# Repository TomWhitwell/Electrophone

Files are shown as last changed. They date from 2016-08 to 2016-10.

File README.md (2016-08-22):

# Electrophone

Electrophone is a Eurorack module containing a full-sized single coil guitar pickup.  

This module is a sister to the Mikrophonie Contact Mic Module and Magnetophone Tape Head Module. The Mikrophonie picks up physical vibrations, while Electrophone can hear electromagnetic vibrations. Guitar pickups are designed to convert vibrating metal (strings) into audio, but single coil pickups are also notoriously susceptible to interference of all kinds; hum from transformers, fluorescent lights or even radio signals.

This module is named after the [Epiphone Electrophone](http://www.oldfrets.com/Electrophone.html) an electric guitar from 1935.  

More information: 
- [FAQ](https://github.com/TomWhitwell/Electrophone/wiki/Music-Thing-Electrophone:-FAQ) 
- [BOM](https://github.com/TomWhitwell/Electrophone/wiki/Music-Thing-Elecrophone:-BOM)
- [Troubleshooting](https://github.com/TomWhitwell/Electrophone/wiki/Music-Thing-Electrophone:-Troubleshooting)
- [Demo video at Superbooth 16](https://youtu.be/UVMrQejVZlw?t=3m17s)

Status:  
- August 2016: Finalised circuit 
- May 2016: revised Rev 4 layout trying to get the fuzz circuit to work 
- March 2016: Demonstrated at Superbooth16 in Berlin, with Fuzz circuit bypassed. 
- December 2015: Small component changes in Pickup Board. 
- November 2015: Minor fault in Panel (pickup cutout slightly tight) and major faults in Pickup Board. Rev2 board designed and sent to fab.  
- October 2015: Rev 1 prototype boards sent to fab  



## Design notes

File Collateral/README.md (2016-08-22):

#Gerber Files 

These PCB panels are made by manually editing Gerber files using [Cenon](http://www.cenon.info/). The Eagle .brd files will not produce the finished panel designs.

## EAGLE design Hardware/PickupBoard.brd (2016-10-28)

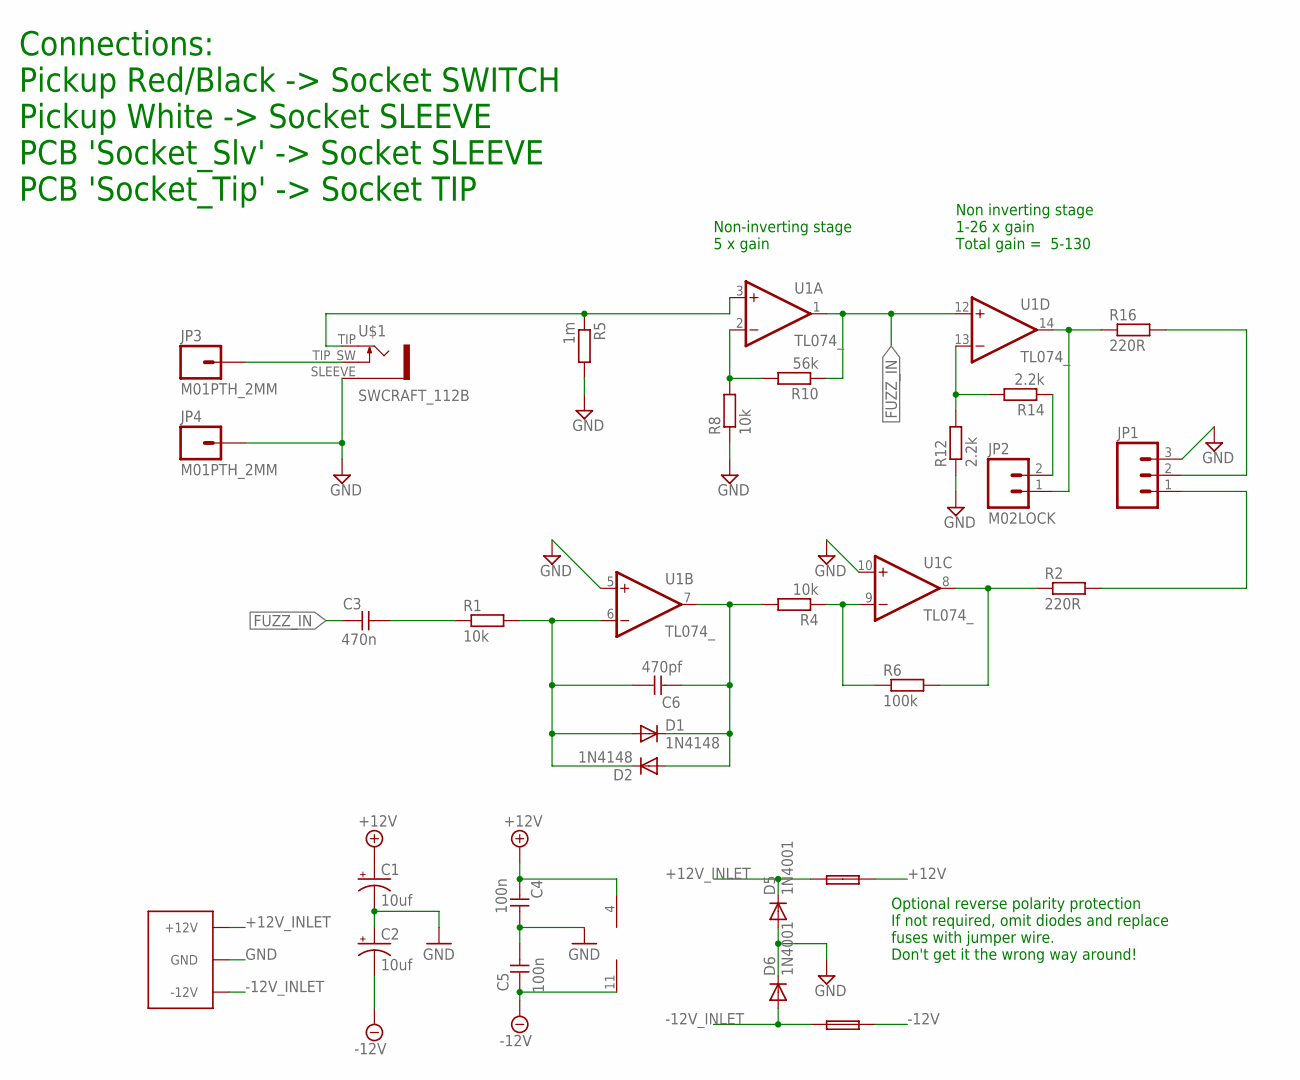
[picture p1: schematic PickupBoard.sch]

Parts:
1: FUSE; C050H075X075
C1, C2: 10uf; CPOL-RADIAL-10UF-25V
C3: 470n; C050-024X044
C4, C5: 100n; C050-024X044
C6: 470pf; C050-024X044
D1, D2: 1N4148; DO35-7
D5, D6: 1N4001; DO41-10
FUSE: FUSE; C050H075X075
JP1: M03LOCK; 1X03_LOCK
JP2: M02LOCK; 1X02_LOCK
JP3, JP4: M01PTH_2MM; 1X01_2MM
R1, R4, R8: 10k; 7MM_RESISTOR
R2, R16: 220R; 7MM_RESISTOR
R5: 1m; 7MM_RESISTOR
R6: 100k; 7MM_RESISTOR
R10: 56k; 7MM_RESISTOR
R12, R14: 2.2k; 7MM_RESISTOR
U1: TL074_; DIL14
U$1: SWCRAFT_112B; SWCRAFT_112_SLOTS
U$2: EURO_POWER_LOCK; EURO_PWR_HEADER_LOCK

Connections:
+12V: 1.2, C1.1 (+), C4.2, U1.4 (V+)
+12V_INLET: 1.1, D5.C, U$2.POS1 (+12V), U$2.POS2 (+12V)
-12V: C2.2 (-), C5.2, FUSE.2, U1.11 (V-)
-12V_INLET: D6.A, FUSE.1, U$2.NEG1 (-12V), U$2.NEG2 (-12V)
FUZZ_IN: C3.2, R10.1, U1.1 (OUT), U1.12 (+IN)
GND: C1.2 (-), C2.1 (+), C4.1, C5.1, D5.A, D6.C, JP1.3, JP4.1, R5.2, R8.1, R12.1, U1.5 (+IN), U1.10 (+IN), U$1.SLEEVE (5), U$2.GND1 (GND), U$2.GND2 (GND), U$2.GND3 (GND), U$2.GND4 (GND), U$2.GND5 (GND), U$2.GND6 (GND)
unnamed: R5.1, U1.3 (+IN), U$1.TIP (3)
unnamed: C6.2, D1.C, D2.A, R4.2, U1.7 (OUT)
unnamed: R8.2, R10.2, U1.2 (-IN)
unnamed: C6.1, D1.A, D2.C, R1.2, U1.6 (-IN)
unnamed: JP2.2, R14.1
unnamed: R12.2, R14.2, U1.13 (-IN)
unnamed: C3.1, R1.1
unnamed: JP2.1, R16.1, U1.14 (OUT)
unnamed: R4.1, R6.1, U1.9 (-IN)
unnamed: JP1.2, R16.2
unnamed: R2.1, R6.2, U1.8 (OUT)
unnamed: JP1.1, R2.2
unnamed: JP3.1, U$1.TIP_SW (4)

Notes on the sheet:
Non-inverting stage 5 x gain
Non inverting stage 1-26 x gain Total gain = 5-130
Optional reverse polarity protection If not required, omit diodes and replace fuses with jumper wire. Don't get it the wrong way around!
Connections: Pickup Red/Black -> Socket SWITCH Pickup White -> Socket SLEEVE PCB 'Socket_Slv' -> Socket SLEEVE PCB 'Socket_Tip' -> Socket TIP

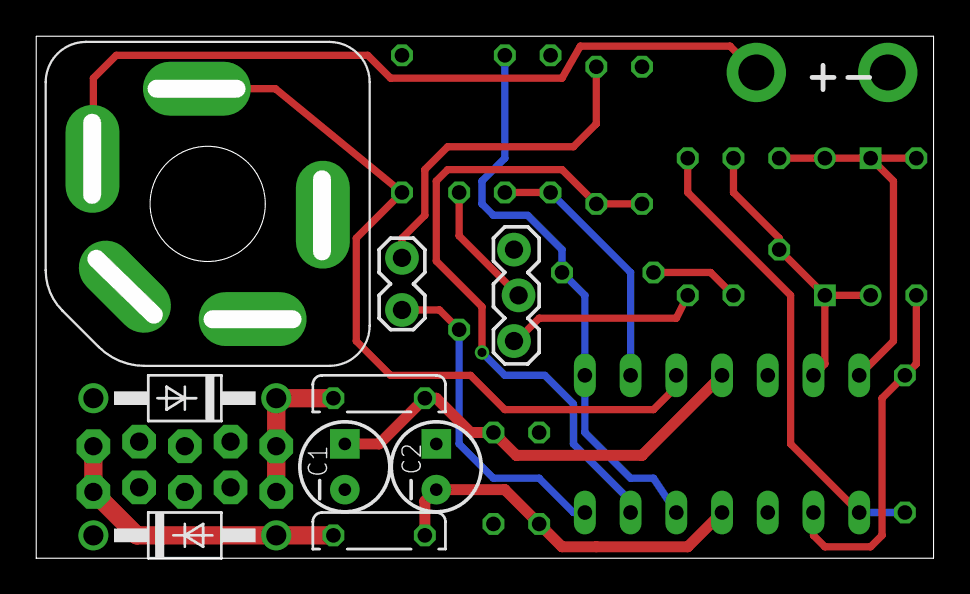
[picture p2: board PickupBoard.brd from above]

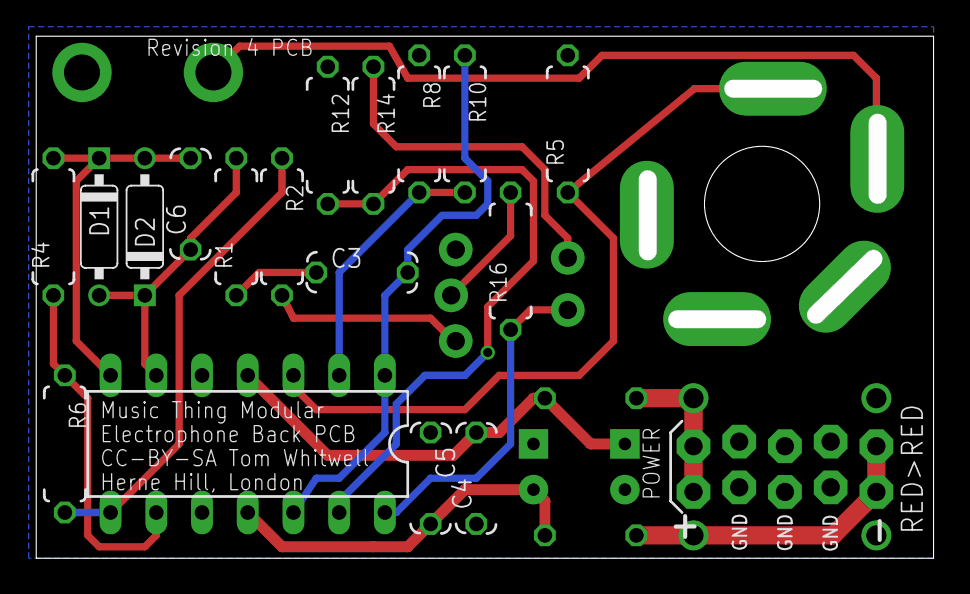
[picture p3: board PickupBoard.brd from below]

Board: 4 copper layers, 49.9 x 29.0 mm, 29 parts (20 on the bottom side), 19 nets.

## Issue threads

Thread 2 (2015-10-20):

Main board has components on the wrong sides

TomWhitwell, 2015-10-20:
What's on the front should be on the back, and vice versa

Closed 2015-11-30.

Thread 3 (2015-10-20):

Pinout on 1/4" socket is completely wrong

TomWhitwell, 2015-10-20:

Closed 2015-11-30.

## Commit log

2015-10-01 early board layout
    [PickupBoard.brd, PickupBoard.sch, PickupPanel.brd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]
2015-10-03 Building the circuit
    [PickupBoard.brd, PickupBoard.sch, PickupPanel.brd]
2015-10-04 Completed first layout
    [PickupBoard.brd, PickupBoard.sch, PickupDaughterBoard.brd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]
2015-10-04 First prototypes completed and sent to fab
    [PickupBoard.brd, PickupBoard.sch, PickupDaughterBoard.brd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]
2015-10-18 Simple alt panel
    [PickupPanel_simpler.brd, PickupPanel_simpler.sch]
2015-10-19 Grow Pickup cutout
    fixes #1
    [PickupPanel.brd, PickupPanel_simpler.brd]
2015-11-29 New Fuzz Circuit with clipping diodes
    not yet laid out
    [PickupBoard_2.brd, PickupBoard_2.sch]
2015-11-30 Rev2 Pickup Board finished and routed
    Panel and Daughterboard unchanged fixes #2, fixes #3, fixes #4
    [PickupBoard.brd, PickupBoard.sch, PickupBoard_2.brd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]
2015-12-22 notes for changes to fix high frequency oscillation
    [PickupBoard.sch]
2015-12-23 Value changes + new cap
    [PickupBoard.brd, PickupBoard.sch]
2016-01-01 Small routing changes
    [PickupBoard.brd]
2016-01-01 Update pickup cutout
    [PickupPanel.brd]
2016-04-10 Reworked layout to reduce noise / feedback
    [PickupBoard.brd, PickupBoard.sch]
2016-05-08 Rev 4 pcb
    [PickupBoard.brd, PickupBoard.sch, PickupDaughterBoard.brd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]
2016-08-22 Clean up files
    [PickupDaughterBoard.brd, PickupDaughterBoard.sch, PickupPanel.brd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]
2016-08-22 Create Gerbers and Edit
    [PickupPanel_simpler.brd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]
2016-08-22 Rename folder
    [PickupBoard.drills.xln, PickupDaughterBoard.drills.xln, PickupPanel.drills.xln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]
2016-08-22 Update panel eagle files removing old logos
    [PickupPanel.brd, PickupPanel_simpler.brd]
2016-10-28 Change name on back pcbs
    [PickupBoard.brd]
2017-02-27 Remove old Gerber
    [PickupBoard.drills.xln, PickupDaughterBoard.drills.xln, PickupPanel.drills.xln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]

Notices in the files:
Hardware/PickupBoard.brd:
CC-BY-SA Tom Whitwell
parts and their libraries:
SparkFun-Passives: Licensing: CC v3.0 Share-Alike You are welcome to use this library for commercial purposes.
